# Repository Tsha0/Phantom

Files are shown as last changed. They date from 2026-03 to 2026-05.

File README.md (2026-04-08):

# Phantom

Developing an Arduino-Enabled Dynamic Ventricular Phantom for Evaluating Microvascular Lung Hydraulic Resistance

## Overview

Phantom is a real-time cardiovascular flow and pressure simulation system. It uses servo motors as variable-resistance valves and records data from flow and pressure sensors at 4 Hz. The system has two layers:

- **Arduino firmware** (`Phantom.ino`) -- controls 3 servos via an Adafruit PCA9685 I2C driver and reads 3 flow sensors + 3 pressure sensors.
- **Python GUI** (`Phantom_GUI.py`) for live monitoring, servo control, and session recording.

## Requirements

### Hardware

- **Arduino Uno**
  [Arduino Uno Rev3](https://store-usa.arduino.cc/products/arduino-uno-rev3?queryID=undefined&selectedStore=us)
- **Adafruit PCA9685 16-Channel Servo Driver** -- drives the servos from an external 7.4 V supply.
  [Adafruit PCA9685](https://www.adafruit.com/product/815)
- **3 Servo Motors** (FR5311M, 4.8-8.4 V, 13.8 kg-cm at 7.4 V) -- act as variable resistance valves (PV, CR1, CR2).
- **3 Flow Sensors** (YF-S401, 0.3-6 L/min, 5880 pulses/L) -- connected to digital pins D8, D7, D5.
- **3 Pressure Sensors** (0-10 PSI, 0.5-4.5 V output) -- connected to analog pins A0, A1, A2.
- **DC Power Supply** (7.4 V for the servo driver).



**Figure 1: Arduino Hardware Configuration**

### Software

- **Arduino IDE** with the `Adafruit_PWMServoDriver` library.
- **Python 3.x** with `pyserial`, `matplotlib`, and `Pillow`.

## Installation

### Hydraulic Setup

The circuit connects a **Left Pump** and **Right Pump** (Pulsatile Pump P-120, TRANDOMED) through four parallel pathways that model fetal cardiovascular shunts:

| Pathway | Components |
|---|---|
| **Pulmonary Veins & Arteries** | Compliance chamber, valve, flow sensor, pressure sensor |
| **Foramen Ovale** | Valves, flow sensor, pressure sensor |
| **PDA (Patent Ductus Arteriosus)** | Valve, flow sensor, pressure sensor |
| **Systemic Veins & Arteries** | Compliance chambers, flow sensor, pressure sensor |

Each pathway carries a combination of servo-driven valves (variable resistance), flow sensors, pressure sensors, and compliance chambers. The valves on the Foramen Ovale and PDA pathways simulate the adjustable shunts controlled by the Arduino.

Additional parts:
- 1/4" tubing, Y fittings, and tee joints
- 1/4" male-to-male straight hex adapters (for inline pressure sensor mounting)

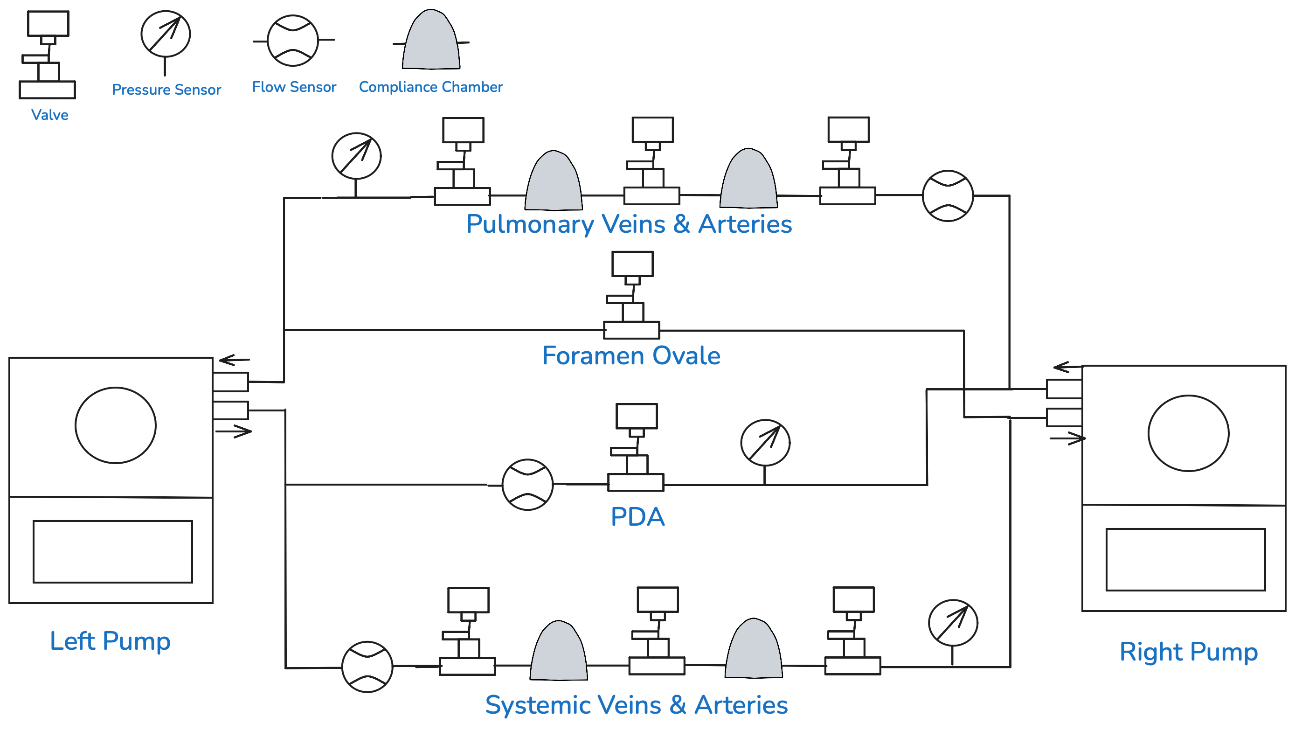
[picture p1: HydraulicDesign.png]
Hydraulic Design


**Figure 2: Hydraulic Circuit Design**

### Arduino Setup

1. Install the `Adafruit_PWMServoDriver` library in the Arduino IDE.
2. Connect the servos, flow sensors, and pressure sensors to their designated pins.
3. Open `Phantom.ino`, compile, and upload.

### Python Setup

```bash
pip install pyserial matplotlib Pillow
```

## Usage

### Graphical UI (recommended)

```bash
python Phantom_GUI.py
```

On launch a port-selection dialog lets you connect to the Arduino or run in **Demo Mode** (no hardware needed).

The GUI has three main areas:

| Area | Description |
|---|---|
| **Circuit panel** (left) | Displays the hydraulic design (`HydraulicDesign.png`) scaled to fit, with live sensor-value overlays. Click any sensor overlay to open a dedicated pop-up graph. |
| **Sidebar** (right) | Connection status, servo control (port selector, position slider, Send button, Set All Open/Closed), sensor pin configuration (reassign digital/analog pins at runtime), and session recording controls. |
| **Live graph** (bottom, collapsible) | Scrolling 20-second chart with separate flow (blue) and pressure (red) subplots. Updates at 4 Hz. |

#### Sensor polling

The UI polls the Arduino every **250 ms** (4 readings per second). All 6 sensor values (FL1-FL3, P1-P3) are updated on the circuit overlay and the live graph each cycle.

#### Session recording

1. Click **Start** in the Session section of the sidebar to begin recording.
2. Every poll cycle, sensor readings are buffered in memory.
3. Click **Stop**, then **Save** to export a timestamped CSV to the `data/` folder (e.g. `data/Session_2026-04-07_143022.csv`).

The CSV contains columns: `timestamp, fl1, fl2, fl3, p1, p2, p3`.

#### Servo control

- Select a PCA9685 **port** (0-15) and a **position** (200-350 ticks, where 200 = closed, 350 = open).
- Move the slider or type the value, then press **Send** (or Enter).
- **Set All Closed / Set All Open** sends the min/max position to all 16 channels at once.

## Project Structure

```
Phantom/
  Phantom.ino               # Arduino firmware
  PhantomController.py       # Serial controller class
  Phantom_GUI.py             # GUI entry point
  HydraulicDesign.png        # Background image for the GUI
  data/                      # Session CSV output (git-ignored)
  UI/
    app.py                   # Main tkinter window
    circuit_panel.py         # Hydraulic diagram with sensor overlays
    control_panel.py         # Servo + pin config sidebar
    graph_panel.py           # Matplotlib live scrolling chart
    sensor_graph.py          # Per-sensor pop-up graph windows
    session.py               # CSV session recorder
    connection.py            # Port selection dialog
    constants.py             # Pins, colors, polling rate, paths
```

## Serial Protocol

| Direction | Message | Description |
|---|---|---|
| UI -> Arduino | `READ\n` | Request latest sensor data |
| Arduino -> UI | `fl1,fl2,fl3,p1,p2,p3\n` | CSV response (L/min, mmHg) |
| UI -> Arduino | `servo <port> <position>\n` | Move one servo (port 0-15, position 200-345 ticks) |
| UI -> Arduino | `SETPINS fl1,fl2,fl3,p1,p2,p3\n` | Reassign sensor pins at runtime |
| Arduino -> UI | `READY\n` | Sent once after startup init sweep completes |

## Troubleshooting

- **No ports detected** -- make sure the Arduino is connected via USB and the correct driver is installed. On macOS, look for `/dev/cu.usbmodem*`.
- **Sensor readings stuck at 0** -- verify physical wiring matches the pin assignments shown in the GUI sidebar. Use the pin-config dropdowns to reassign if needed.
- **Servo not moving** -- confirm the PCA9685 is powered (7.4 V external supply) and the I2C address is default (0x40).

## License

This project is shared under the MIT License. See the [LICENSE](LICENSE) file for details.

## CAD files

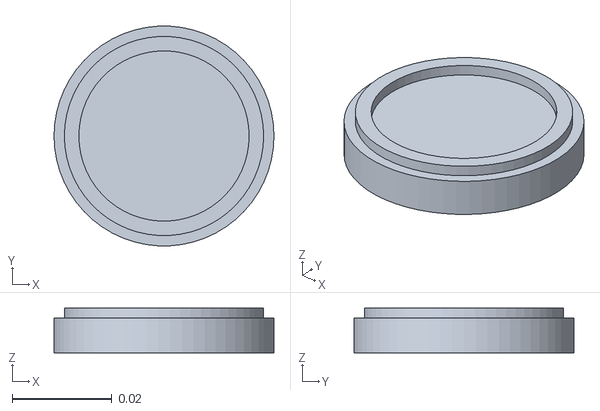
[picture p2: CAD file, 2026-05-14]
3D printed parts/Slip Bottom.stl
0.044 x 0.0439 x 0.009

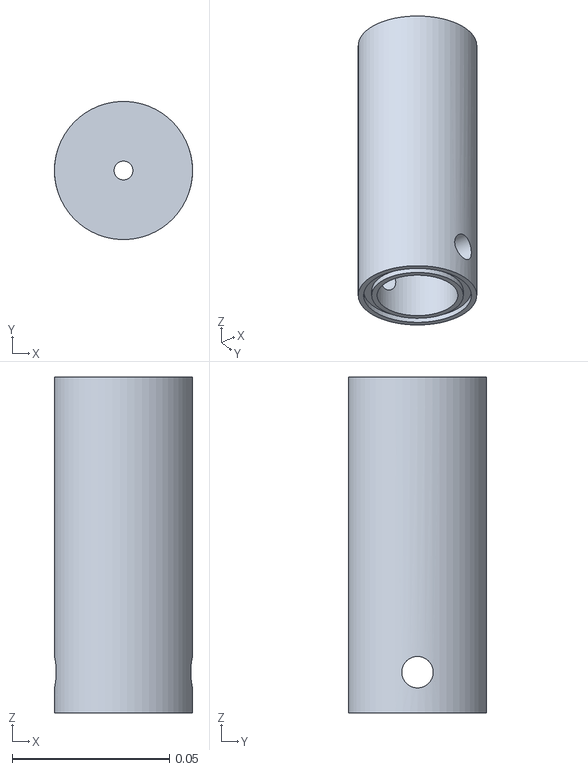
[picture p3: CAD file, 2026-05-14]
3D printed parts/Slip Top.stl
0.044 x 0.0439 x 0.107

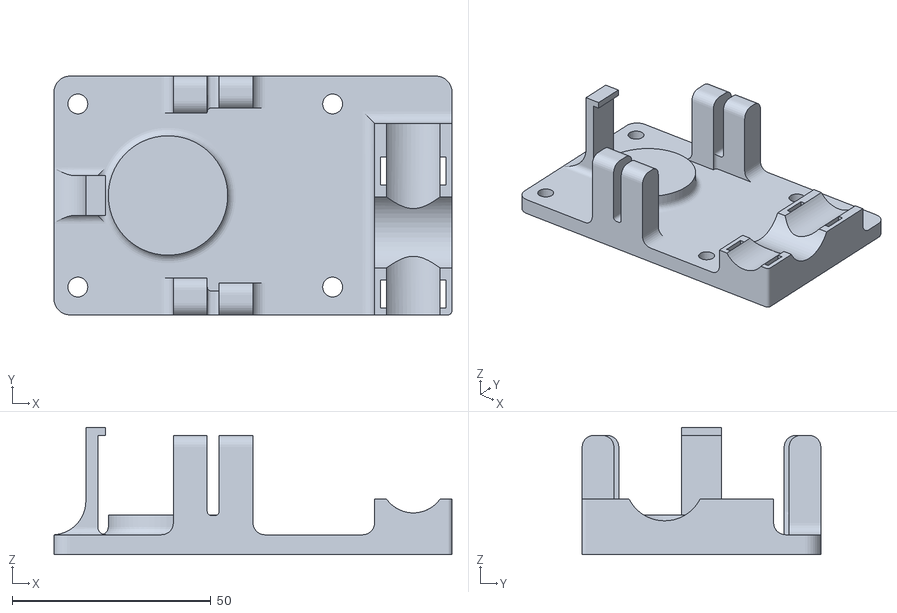
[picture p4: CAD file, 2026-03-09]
3D printed parts/Valve support.stl
100.0 x 60.0 x 32.0

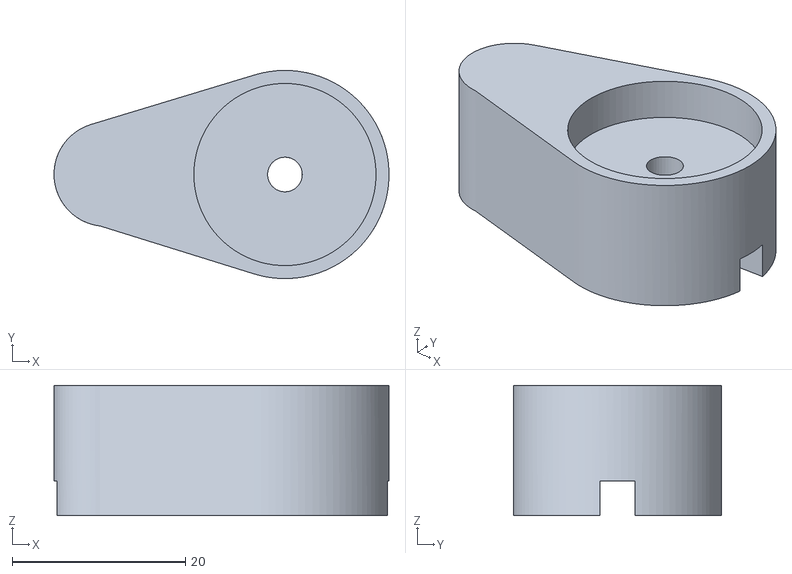
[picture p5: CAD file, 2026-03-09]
3D printed parts/Valve_Servo connection.stl
38.6 x 24.0 x 15.0

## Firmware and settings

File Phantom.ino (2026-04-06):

/*
  Phantom — Dynamic Ventricular Phantom firmware

  Servo motors (PCA9685 I2C PWM driver, channels 0-15):
    CR1 (ch 0)    CR2 (ch 1)    CR3 (ch 2)    CR4 (ch 3)

  Flow sensors (digital interrupt, YF-S401 — 5880 pulses/L):
    FL1 — pin 8    FL2 — pin 7    FL3 — pin 5    FL4 — pin 3

  Pressure sensors (analog, 0-10 PSI, 0.5-4.5 V output):
    P1 — A0    P2 — A1    P3 — A2    P4 — A3

  Serial protocol:
    RX  "READ\n"                        → TX latest cached sensor CSV
    RX  "servo <port> <position>\n"     → move one servo (port 0-15, position 200-345 ticks)
    TX  "fl1,fl2,fl3,fl4,p1,p2,p3,p4\n"→ CSV in L/min and mmHg
    TX  "READY\n"                       → sent once after init sweep completes

  All sensor reading and servo movement are non-blocking (millis-based).
*/

#include <Adafruit_PWMServoDriver.h>

Adafruit_PWMServoDriver pwm = Adafruit_PWMServoDriver();

// Servo tick range (uniform for all servos)
const int SERVO_CLOSE = 200;
const int SERVO_OPEN  = 345;

// Non-blocking gradual movement state (16 PCA9685 channels)
int currentPos[16];
int targetPos[16];
unsigned long lastStepTime[16];
const unsigned long STEP_INTERVAL_MS = 10;

int flowSensorPins[] = {8, 7, 5, 3};
int pressureSensorPins[] = {A0, A1, A2, A3};

const float PULSES_PER_LITER = 5880.0;
const float PSI_TO_MMHG = 51.715;
const float PSI_MAX = 10.0;
const float V_MIN = 0.5;
const float V_MAX = 4.5;
const float VCC = 5.0;

volatile int pulseCount[] = {0, 0, 0, 0};

void pulseCounterFL1() { pulseCount[0]++; }
void pulseCounterFL2() { pulseCount[1]++; }
void pulseCounterFL3() { pulseCount[2]++; }
void pulseCounterFL4() { pulseCount[3]++; }

typedef void (*ISR_FUNC)();
ISR_FUNC isrFuncs[] = {pulseCounterFL1, pulseCounterFL2, pulseCounterFL3, pulseCounterFL4};

// Cached sensor values (updated every SENSOR_INTERVAL_MS)
float latestFlow[4] = {0, 0, 0, 0};
float latestPressure[4] = {0, 0, 0, 0};
unsigned long lastSensorUpdate = 0;
const unsigned long SENSOR_INTERVAL_MS = 1000;

void setup() {
  Serial.begin(9600);
  pwm.begin();
  pwm.setPWMFreq(60);

  for (int i = 0; i < 4; i++) {
    pinMode(flowSensorPins[i], INPUT_PULLUP);
    attachInterrupt(digitalPinToInterrupt(flowSensorPins[i]), isrFuncs[i], RISING);
  }

  // Initialize all channel tracking to closed position
  for (int i = 0; i < 16; i++) {
    currentPos[i] = SERVO_CLOSE;
    targetPos[i]  = SERVO_CLOSE;
    lastStepTime[i] = 0;
  }

  // Initialization sweep: close -> open -> close on channels 0-3
  for (int tick = SERVO_CLOSE; tick <= SERVO_OPEN; tick++) {
    for (int i = 0; i < 4; i++) {
      pwm.setPWM(i, 0, tick);
    }
    delay(10);
  }
  for (int tick = SERVO_OPEN; tick >= SERVO_CLOSE; tick--) {
    for (int i = 0; i < 4; i++) {
      pwm.setPWM(i, 0, tick);
    }
    delay(10);
  }

  // All servos now at SERVO_CLOSE
  for (int i = 0; i < 4; i++) {
    currentPos[i] = SERVO_CLOSE;
    targetPos[i]  = SERVO_CLOSE;
  }

  lastSensorUpdate = millis();
  Serial.println("READY");
}

void loop() {
  unsigned long now = millis();

  // 1. Process incoming serial commands
  if (Serial.available() > 0) {
    String command = Serial.readStringUntil('\n');
    command.trim();
    if (command == "READ") {
      sendSensorData();
    } else if (command.startsWith("servo ")) {
      parseServoCommand(command);
    } else if (command.startsWith("SETPINS ")) {
      parseSetPinsCommand(command);
    }
  }

  // 2. Non-blocking sensor update (every 1 second)
  if (now - lastSensorUpdate >= SENSOR_INTERVAL_MS) {
    noInterrupts();
    int counts[4];
    for (int i = 0; i < 4; i++) {
      counts[i] = pulseCount[i];
      pulseCount[i] = 0;
    }
    interrupts();

    for (int i = 0; i < 4; i++) {
      latestFlow[i] = max(counts[i] / (PULSES_PER_LITER / 60.0), 0.0);
      latestPressure[i] = max(readPressureSensor(pressureSensorPins[i]), 0.0);
    }
    lastSensorUpdate = now;
  }

  // 3. Non-blocking gradual servo movement
  for (int i = 0; i < 16; i++) {
    if (currentPos[i] != targetPos[i] && (now - lastStepTime[i] >= STEP_INTERVAL_MS)) {
      if (currentPos[i] < targetPos[i]) {
        currentPos[i]++;
      } else {
        currentPos[i]--;
      }
      pwm.setPWM(i, 0, currentPos[i]);
      lastStepTime[i] = now;
    }
  }
}

void sendSensorData() {
  String out = "";
  for (int i = 0; i < 4; i++) {
    if (i > 0) out += ",";
    out += String(latestFlow[i]);
  }
  for (int i = 0; i < 4; i++) {
    out += ",";
    out += String(latestPressure[i]);
  }
  Serial.println(out);
}

float readPressureSensor(int pin) {
  int sensorValue = analogRead(pin);
  float voltage = sensorValue * (VCC / 1023.0);

  float psi;
  if (voltage <= V_MIN) {
    psi = 0.0;
  } else if (voltage >= V_MAX) {
    psi = PSI_MAX;
  } else {
    psi = (voltage - V_MIN) * PSI_MAX / (V_MAX - V_MIN);
  }

  return psi * PSI_TO_MMHG;
}

int parseDigitalPin(String s) {
  // "D3" -> 3, "D8" -> 8, etc.
  if (s.startsWith("D")) return s.substring(1).toInt();
  return s.toInt();
}

int parseAnalogPin(String s) {
  // "A0" -> A0, "A1" -> A1, etc.
  if (s.startsWith("A")) {
    int n = s.substring(1).toInt();
    return A0 + n;
  }
  return s.toInt();
}

void reconfigureFlowInterrupts() {
  // Detach all existing flow interrupts, reset counts, re-attach
  for (int i = 0; i < 4; i++) {
    int intr = digitalPinToInterrupt(flowSensorPins[i]);
    if (intr != NOT_AN_INTERRUPT) {
      detachInterrupt(intr);
    }
  }
  for (int i = 0; i < 4; i++) {
    pulseCount[i] = 0;
    pinMode(flowSensorPins[i], INPUT_PULLUP);
    int intr = digitalPinToInterrupt(flowSensorPins[i]);
    if (intr != NOT_AN_INTERRUPT) {
      attachInterrupt(intr, isrFuncs[i], RISING);
    }
  }
}

void parseSetPinsCommand(String command) {
  // Format: "SETPINS fl1,fl2,fl3,fl4,p1,p2,p3,p4"
  // e.g.    "SETPINS D8,D7,D5,D3,A0,A1,A2,A3"
  String args = command.substring(8);
  args.trim();

  int commaIdx;
  String tokens[8];
  int tokenCount = 0;
  while (tokenCount < 8) {
    commaIdx = args.indexOf(',');
    if (commaIdx == -1) {
      tokens[tokenCount++] = args;
      break;
    }
    tokens[tokenCount++] = args.substring(0, commaIdx);
    args = args.substring(commaIdx + 1);
  }

  if (tokenCount != 8) return;  // need exactly 8 pin values

  for (int i = 0; i < 4; i++) {
    flowSensorPins[i] = parseDigitalPin(tokens[i]);
  }
  for (int i = 0; i < 4; i++) {
    pressureSensorPins[i] = parseAnalogPin(tokens[4 + i]);
  }

  reconfigureFlowInterrupts();
}

void parseServoCommand(String command) {
  // Format: "servo <port> <position>"
  int firstSpace = command.indexOf(' ', 6);
  if (firstSpace == -1) return;

  int port = command.substring(6, firstSpace).toInt();
  int position = command.substring(firstSpace + 1).toInt();

  if (port < 0 || port > 15) return;
  position = constrain(position, SERVO_CLOSE, SERVO_OPEN);

  targetPos[port] = position;
}

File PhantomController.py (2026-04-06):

import os
import random
import serial
import serial.tools.list_ports
import sys
import time
from datetime import datetime

def list_serial_ports():
    """List available serial ports."""
    ports = list(serial.tools.list_ports.comports())

    # Filter for common macOS Arduino port patterns
    arduino_ports = []
    other_ports = []

    for p in ports:
        device = p.device
        # Common Arduino patterns on macOS
        if any(pattern in device for pattern in ['usbmodem', 'usbserial', 'wchusbserial', 'SLAB']):
            arduino_ports.append(p)
        else:
            other_ports.append(p)

    return arduino_ports + other_ports

class PhantomController:
    """Controller class for the Phantom Arduino device."""

    def __init__(self, port=None, demo_mode=False):
        self.demo_mode = demo_mode
        self.port = port
        self.ser = None
        self.conditions = None

        if not demo_mode and port:
            try:
                self.ser = serial.Serial(port, 9600, timeout=1)
                time.sleep(2)  # Wait for Arduino to reset after serial connection
                self.wait_for_ready()
                print(f"Connected to {port}")
            except serial.SerialException as e:
                print(f"Error opening serial port: {e}")
                sys.exit(1)

    def wait_for_ready(self, timeout=10):
        """Block until Arduino sends 'READY' or timeout expires."""
        if self.demo_mode:
            return True

        start = time.time()
        buffer = ""
        while time.time() - start < timeout:
            if self.ser.in_waiting > 0:
                buffer += self.ser.read(self.ser.in_waiting).decode(errors='replace')
                if "READY" in buffer:
                    print("Arduino initialization complete")
                    return True
            time.sleep(0.1)

        print(f"Warning: Arduino READY not received within {timeout}s")
        return False

    def request_sensor_data(self):
        """Request and return sensor data from Arduino or generate mock data."""
        if self.demo_mode:
            flows = [round(random.uniform(0.5, 2.0), 2) for _ in range(4)]
            pressures = [round(random.uniform(5, 15) * 51.715, 1) for _ in range(4)]
            return ",".join(str(v) for v in flows + pressures)

        self.ser.reset_input_buffer()
        self.ser.write(b"READ\n")
        timeout_counter = 0
        while self.ser.in_waiting <= 0:
            time.sleep(0.1)
            timeout_counter += 1
            if timeout_counter > 50:  # 5 second timeout
                return "0,0,0,0,0,0,0,0"
        data = self.ser.readline().decode().strip()
        return data

    def send_servo_command(self, port, position):
        """Send a single servo command. Format: servo <port> <position>"""
        command = f"servo {port} {position}\n"

        if self.demo_mode:
            print(f"[Demo] {command.strip()}")
            return

        self.ser.write(command.encode())
        self.ser.flush()

    def send_pin_config(self, pin_map: dict):
        """Send pin assignments to Arduino. Format: SETPINS fl1,fl2,fl3,fl4,p1,p2,p3,p4"""
        keys = ["fl1", "fl2", "fl3", "fl4", "p1", "p2", "p3", "p4"]
        values = [pin_map.get(k, "") for k in keys]
        command = f"SETPINS {','.join(values)}\n"

        if self.demo_mode:
            print(f"[Demo] {command.strip()}")
            return

        self.ser.write(command.encode())
        self.ser.flush()

    def update_conditions(self, conditions):
        """Send servo positions to Arduino based on condition percentages.

        Conditions tuple: (cr1%, cr2%, cr3%, cr4%, pump_left, pump_right, temp)
        Converts percentage (0-100) to tick range (SERVO_CLOSE=200 to SERVO_OPEN=345).
        """
        SERVO_CLOSE = 200
        SERVO_OPEN = 345

        servo_percentages = conditions[:4]
        for channel, pct in enumerate(servo_percentages):
            ticks = int(SERVO_CLOSE + (pct / 100.0) * (SERVO_OPEN - SERVO_CLOSE))
            self.send_servo_command(channel, ticks)

    def close(self):
        """Close serial connection."""
        if self.ser and self.ser.is_open:
            self.ser.close()

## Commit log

2026-03-09 Implement Phantom UI for Arduino communication with sensor data logging and demo mode
    - Added `Phantom_UI_Modified.py` for cross-platform serial port selection, demo mode, and data logging.
    - Created `sensortesting.ino` for testing pressure and flow sensors with interrupt handling.
    - Enhanced user interaction for selecting serial ports and inputting conditions.
    - Implemented formatted output for sensor readings and conditions.
    - Added error handling for serial port connections and user inputs.
    [Valve support.stl, Valve_Servo connection.stl]
2026-03-10 Add servo functionality test with PCA9685 support
2026-03-14 servo test
2026-03-29 new UI creation
    [Session_2026-03-29_005051.csv, Session_2026-03-29_005108.csv]
2026-03-29 change up servo motor control settings
2026-04-05 Enhance sensor data handling with caching and non-blocking updates
2026-04-05 Fix Phantom_UI to work with 4-channel servo/sensor Arduino firmware
    Add missing imports of PhantomController and list_serial_ports, add
    update_conditions method to convert servo percentages to PWM ticks,
    and update UI to handle 4 servos and 8 sensor values (4 flow + 4 pressure).
    [PhantomController.py]
2026-04-06 Implement dynamic pin configuration and enhance UI controls for servo managemen
2026-04-08 remove and arcive file
    [Session_2026-03-29_005051.csv, Session_2026-03-29_005108.csv]
2026-04-08 Update README to reflect removed files (CLI, calibration sketches, tests)
2026-04-08 Update sensor overlay positions and comments in constants.py
2026-05-14 Add CAD compliance chamber via upload
    Contact clementine.ruiz@mail.mcgill.ca for onshape access
    [Slip Bottom.stl, Slip Top.stl]
